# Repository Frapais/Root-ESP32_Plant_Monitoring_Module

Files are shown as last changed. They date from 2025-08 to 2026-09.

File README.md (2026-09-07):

# Root - Complete Plant Monitoring Module

This is the repository of my **Root** project, a complete plant monitoring system, consisting of a Capacitive Soil Moisture Sensor, an Ambient Light sensor, and an Air Temperature & Humidity sensor.
By directly soldering a [Sprig ESP32](https://www.tindie.com/products/spriglabs/sprig-esp32-c3-development-board/) board, you can make a battery powered plant monitoring sensor for Home Assistant.

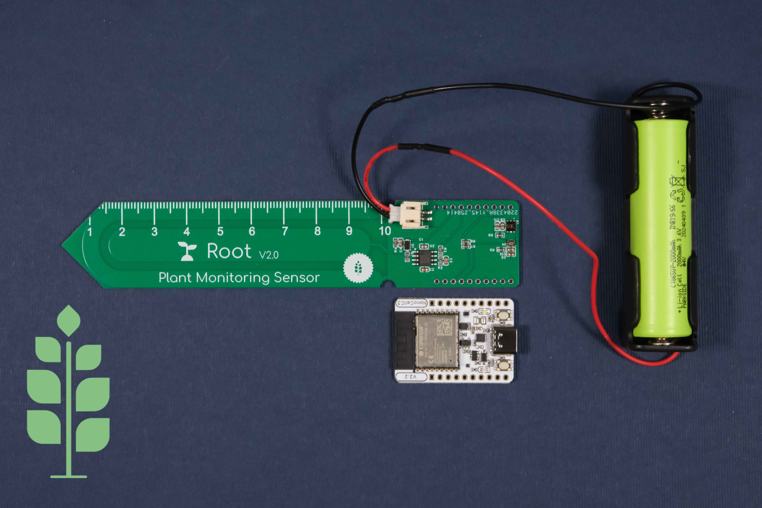
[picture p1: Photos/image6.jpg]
||Pinout|
|-|-|

## 🔋 Free ESPHome battery pack
Building battery-powered ESP32 sensors? Check out this battery-life
calculator (works with any ESP32 board):
**→ [Get the free pack](https://sprig-labs.com/esp32-battery-life-calculator/?utm_source=github&utm_medium=readme)**

## Description
### Hardware
The soil moisture is measured by measuring the varying capacitance of the sensor's surface. If everything else stays constant, the capacitance will change with the change of the water content in the soil.
The sensor outputs an varying voltage corresponding to the change in capacitance, which we can measure via an analog input of any microcontroller.

#### Main Features
* Corrosion-resistant soil moisture sensor
* I2C Ambient light sensor
* I2C Air temperature & humidity sensor
* GPIO-controlled power supply for low power consumption
* LiPo battery connector

### Tests
To test this sensor, a [Sprig ESP32 development board](https://www.tindie.com/products/spriglabs/sprig-esp32-c3-development-board/) board was soldered to the corresponding pins, and the raw values of the sensor were continously uploaded to the local Home Assistant server.
The analog input was read with 11dB attennuation, and the maximum values were **1.8V** with a completely dry sensor, and **0.89V** when the sensor was submerged in a glass of water.
These valuse can be mapped into a percentage of **0%** and **100%** soil moisture accordingly. However, it is recommended to repeat this calibration process when the sensor is placed inside the soil in its final position.

### Initial Home Assistant setup
#### Requirements:
* Access to Home Assistant Dashboard
* Installed ESPHome plugin

#### Setup process:

## Availability
You can get the assembled boards from my [Tindie](https://www.tindie.com/products/spriglabs/root-complete-plant-monitoring-pcb/) shop.



## Support
If you find this project useful, please consider supporting me on any of the following platforms:
* PayPal:
  * <a href="https://www.paypal.com/paypalme/kostasparaskevas">
    
* Buy Me a Coffe:
  * <a href="https://buymeacoffee.com/spriglabs" target="_blank">Buy Me A Coffee</a>
* Instagram:
  * [@sprig-labs](https://www.instagram.com/sprig_labs/)

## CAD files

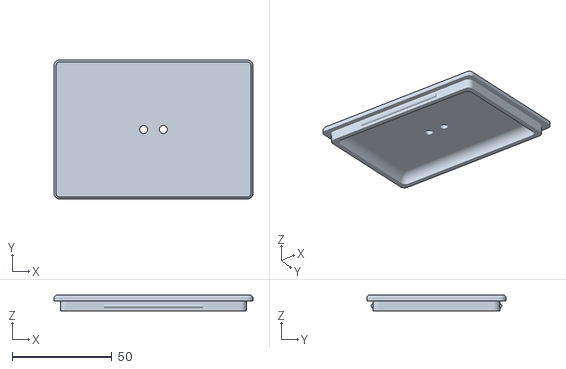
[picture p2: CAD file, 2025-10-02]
Enclosure/Plant sensor enclosure - Lid.stl
100.0 x 70.0 x 8.00

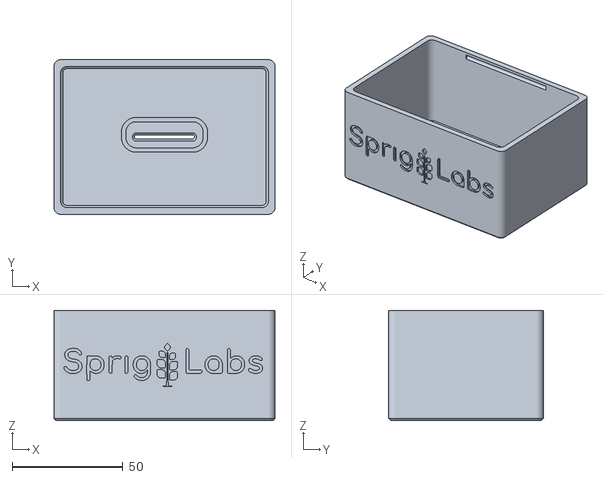
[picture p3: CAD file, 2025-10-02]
Enclosure/Plant sensor enclosure - Body.stl
100.0 x 70.0 x 50.0

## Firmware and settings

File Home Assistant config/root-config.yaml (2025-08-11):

esphome:
  name: root-test
  friendly_name: Root Test
  libraries:
    # Wire library is needed for the i2c protocol
    - "Wire"
  on_boot: 
    then:
      # On boot, give power to the 3 distinct sensors (light, temp, soil moisture)
      - output.turn_on: soil_en
      - output.turn_on: temp_en
      - output.turn_on: light_en
      # If you want to implement deep_sleep, uncomment the following line
      # - script.execute: deep_sleep_evaluation

esp32:
  board: esp32-c3-devkitm-1
  framework:
    type: arduino

# Enable logging
logger:

# Enable Home Assistant API
api:
  encryption:
    key: "USYfAc2WIc5d9Hb/A+V3/qgf2xPWg/f8vUbYgg6ha2Y="

ota:
  - platform: esphome
    password: "928fe8fc1c1970794794c00daf00ca43"

wifi:
  ssid: !secret wifi_ssid
  password: !secret wifi_password

  # Enable fallback hotspot (captive portal) in case wifi connection fails
  ap:
    ssid: "Lemon-Root Fallback Hotspot"
    password: "HePykeJB6cKn"

captive_portal:

# Initiallize the I2C Protocol (NanoCell uses pins 2 and 3)
i2c:
- id: bus_a
  sda: 2
  scl: 3
  scan: True

# Decalaration of the GPIOs that give power to the 3 distinct sensors of the Root.
output:
  - platform: gpio
    pin: 5
    id: soil_en

  - platform: gpio
    pin: 6
    id: temp_en

  - platform: gpio
    pin: 7
    id: light_en

# This is a "toggle" type input_boolean helper, created from the Home Assistant "settings" menu.
# When this binary sensor is "on" the deep sleep will be disabled.
# Be sure to enable deep sleep functionality AFTER you have configured the device on Home Assistant, otherwise this binary sensor state will not be read.
binary_sensor:
  - platform: homeassistant
    id: disable_deep_sleep
    entity_id: input_boolean.disable_deep_sleep

sensor:
  # The implementation of the soil moisture sensor
  - platform: adc
    pin: 4
    name: "Soil moisture"
    update_interval: 10min
    attenuation: 11dB
    filters:
    - calibrate_linear:
        # Map 0.0 (from sensor) to 0.0 (true value)
        - 1.1 -> 0
        - 0.90 -> 100
    unit_of_measurement: '%'
    accuracy_decimals: 0

  # The implementation of the Ambient light sensor
  - platform: veml7700
    address: 0x10
    update_interval: 10min
    # short variant of sensor definition:
    ambient_light: "Ambient light"
    # longer variant of sensor definition:
    actual_gain:
      name: "Actual gain"
  
  # The implementation of the Air temp & humidity sensor
  - platform: hdc1080
    temperature:
      name: "Air Temperature"
    humidity:
      name: "Air Humidity"
    address: 0x40
    update_interval: 10min

  # The implementation of the battery monitoring of the SprigC3
  - platform: max17043
    id: max17043_id
    i2c_id: bus_a
    battery_voltage:
      name: "Battery Voltage"
      accuracy_decimals: 1
    battery_level:
      name: "Battery Level"
      accuracy_decimals: 0
    update_interval: 10min

# This script sets the waiting time before going into sleep mode
# Once the delay time has passed, checks the status of the binary sensor mentioned above
# If the binary sensor status is "on", it disables deep sleep. Otherwise, it enters deep sleep for the set duration
script:
  - id: deep_sleep_evaluation
    mode: queued
    then:
      - delay: 30s
      - if:
          condition:
            binary_sensor.is_on: disable_deep_sleep
          then:
            - logger.log: 'Deep Sleep Disabled'
            - deep_sleep.prevent: deep_sleep_enabled
          else:
            - deep_sleep.enter: deep_sleep_enabled
      - script.execute: deep_sleep_evaluation

# Here, the deep sleep duration is declared
deep_sleep:
  id: deep_sleep_enabled
  sleep_duration: 10min

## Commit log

2025-04-18 Updated HA Configuration for easier battery level monitoring
2025-10-02 Updated photos & 3D files
    [Plant sensor enclosure - Body.stl, Plant sensor enclosure - Lid.stl]
2026-09-07 Add ESPHome battery pack information to README
    Added a section about a free ESPHome battery pack and its calculator.
